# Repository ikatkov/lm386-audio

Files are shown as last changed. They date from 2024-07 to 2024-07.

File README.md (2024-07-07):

# Small audio amplifier

This is LM386-based power amplifier for radio projects. The simplest possible design directly from the datasheet. 

Assembled mostly from salvaged parts and parts of dubious origin.

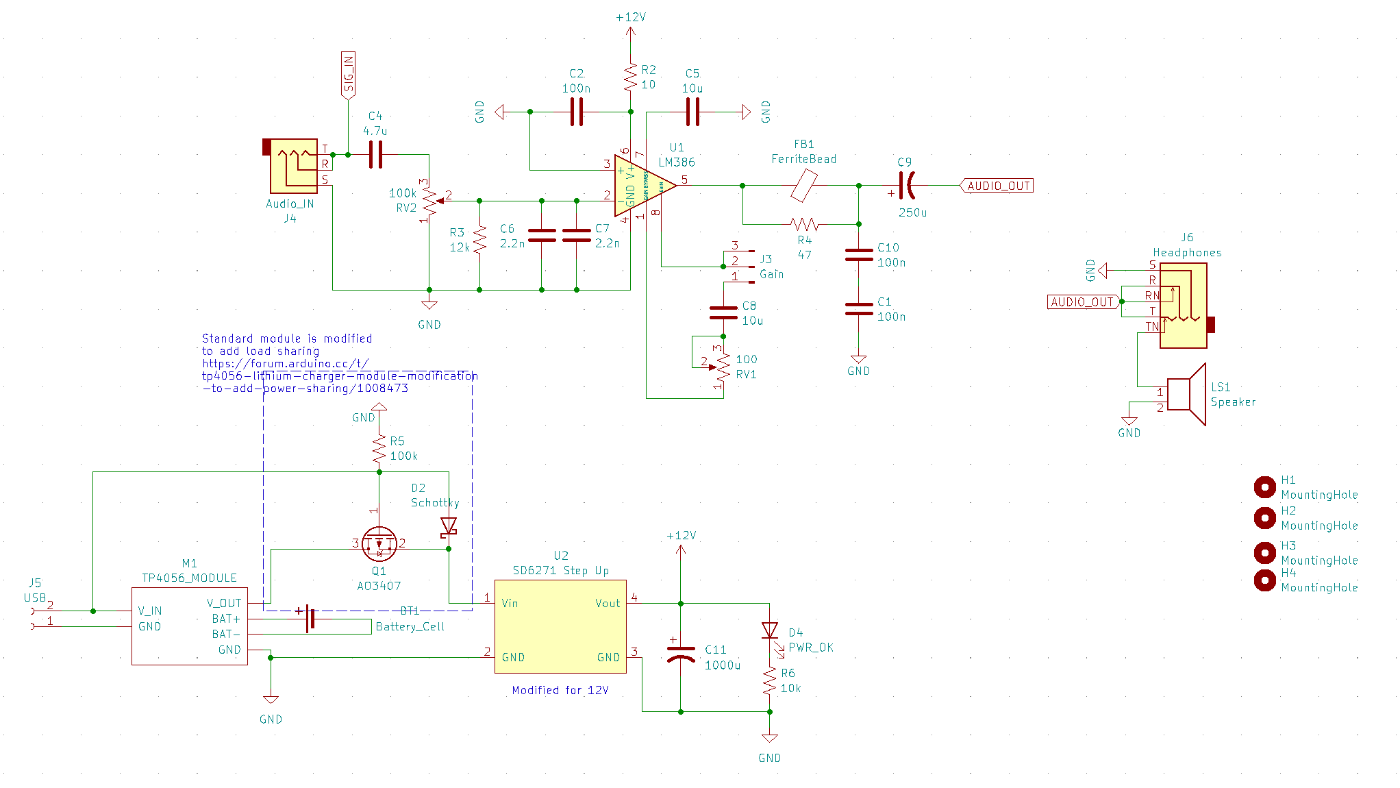
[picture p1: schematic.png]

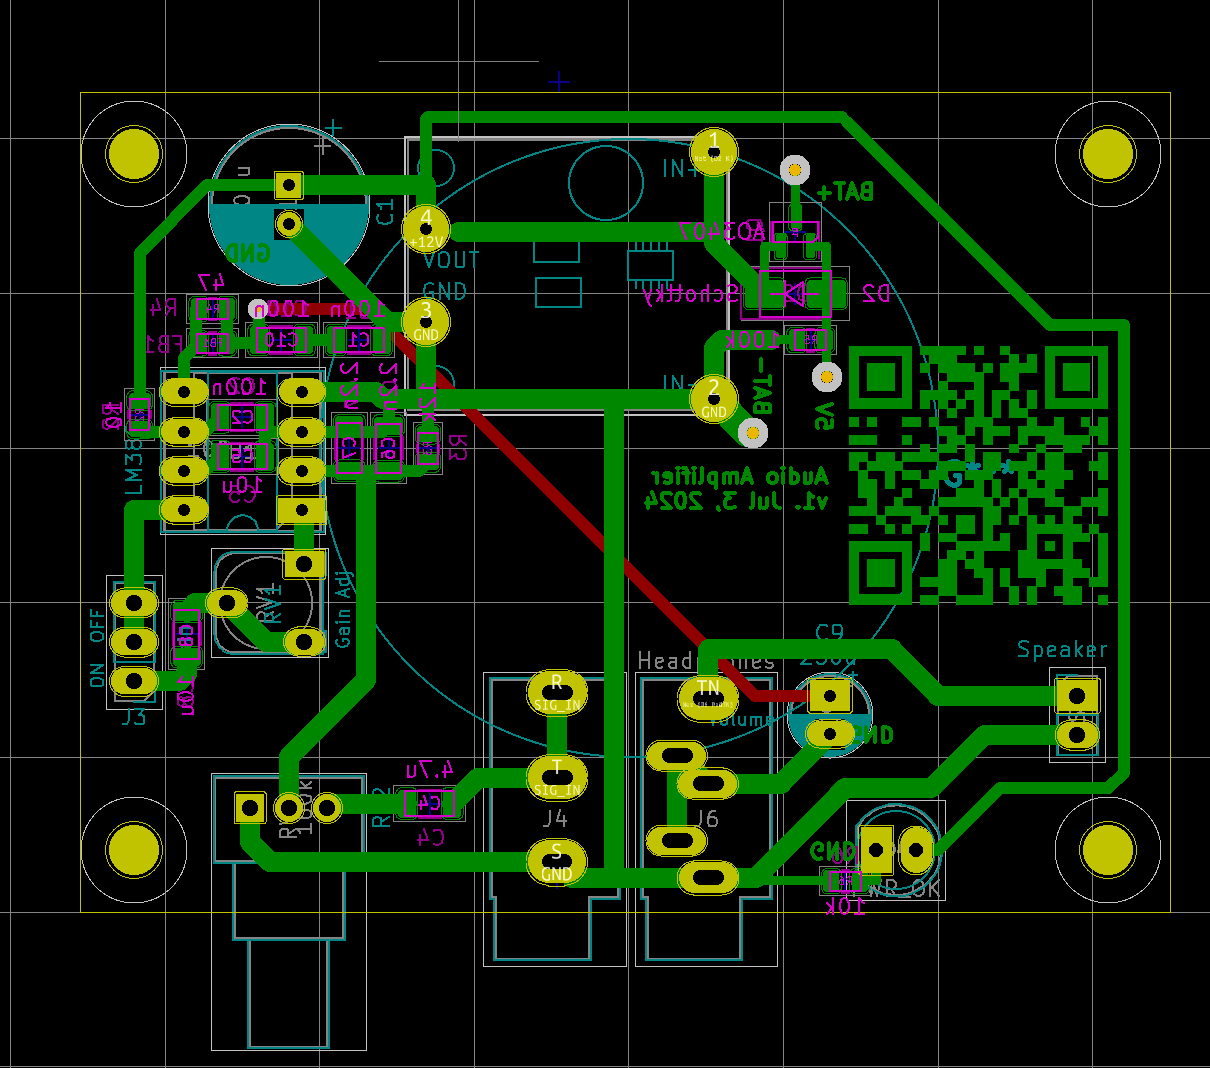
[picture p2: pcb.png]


The charging module and USB socket are not shown on PCB. I had a USB micro socket breakout that I screw directly to the top right corner. USB socket has to stick out from the main board otherwise wide jacks do not fit. The charging module is mounted vertically facing the back panel so that LEDs are visible through the hole.

# Notes

Instead of a hard-to-get 10k logarithmic volume pot, there is a 100k linear with a 12k resistor from the pot wiper to the ground. This is a nice trick.

The output audio signal jack is wired to disconnect the speaker when something, typically headphones, is inserted.

There is a lipo battery inside, with a TP4056 module. The standard PCB was modified for load sharing i.e. when USB power is available, it powers the amplifier directly, bypassing the battery. A  5V boost module

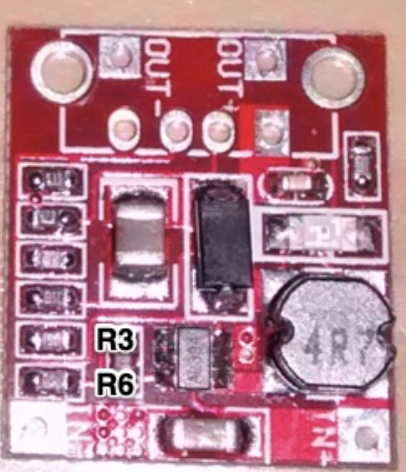
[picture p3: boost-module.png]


was modified for ~12V. Output voltage ripple is ~ 50mV. I presume it is much larger under the load, but the audio amplifier load is very jittery and nonstable as well. LM386 is 0.5W max anyway.

# Enclosure

See 3D printed enclosure files [here](enclosure)

The volume potentiometer stem is not shown. I now assemble first and drill all the holes later. This is significantly faster than high-precision measuring and assembly. 

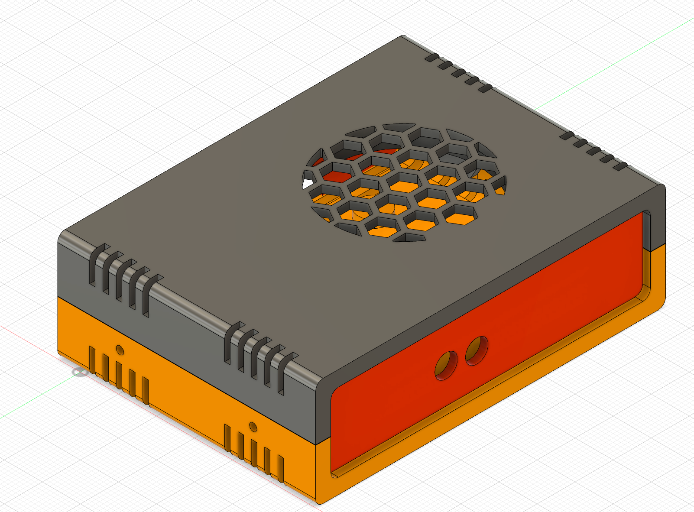
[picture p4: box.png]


# Assembly

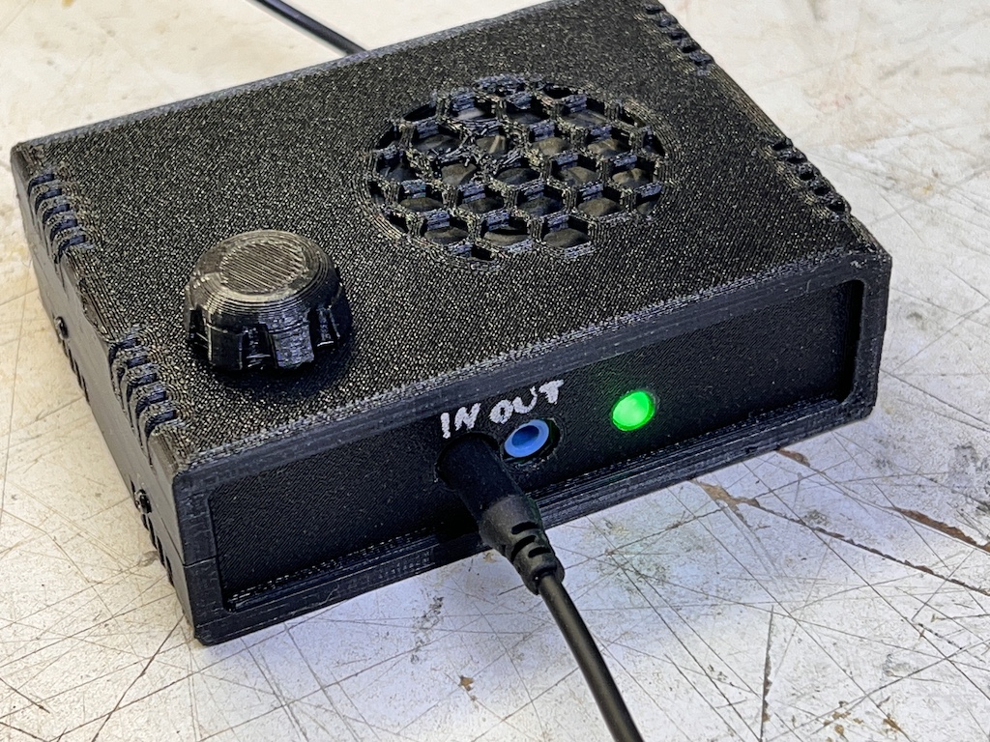
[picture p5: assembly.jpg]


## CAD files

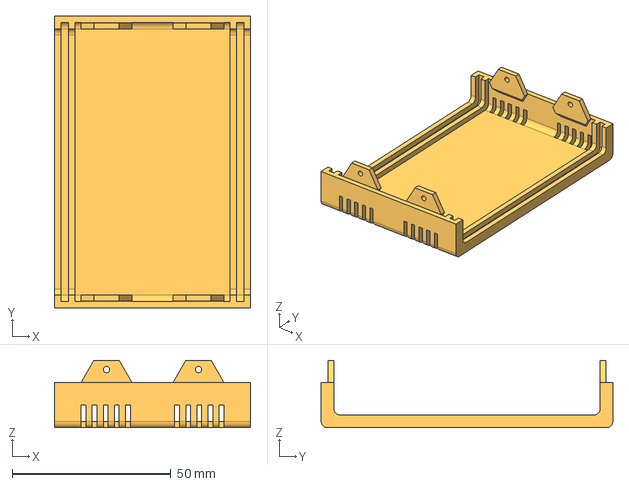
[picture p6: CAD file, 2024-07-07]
enclosure/enclosure-top-shell.step
61.8 x 92.0 x 21.2 mm

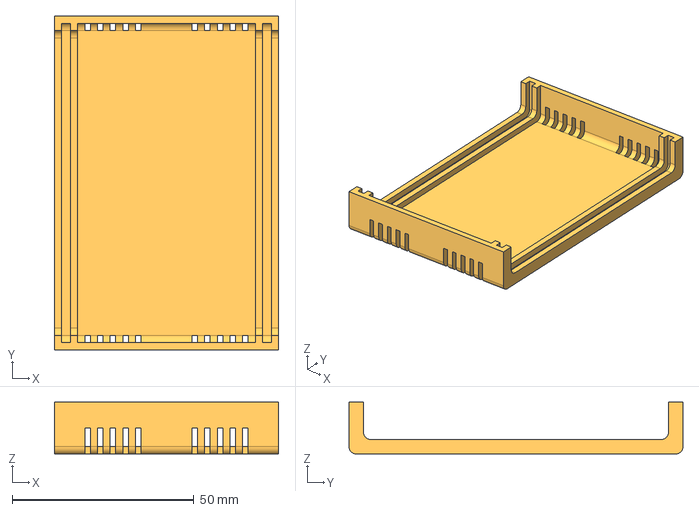
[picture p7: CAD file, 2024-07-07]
enclosure/enclosure-bottom-shell.step
61.8 x 92.0 x 14.3 mm

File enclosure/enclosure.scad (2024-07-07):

/* Box design originally by:
////////////////////////////////////////////////////////////////////
              -    FB Aka Heartman/Hearty 2016     -
              -   http://heartygfx.blogspot.com    -
              -       OpenScad Parametric Box      -
              -         CC BY-NC 3.0 License       -
////////////////////////////////////////////////////////////////////

Improved by jbebel:
http://github.com/jbebel/Ultimate-Box-Maker

To create a box, start by modifying the numerical parameters in the sections
below. This can be accomplished using a release of OpenSCAD newer than 2015.03.
As of the time of writing, this means that a development snapshot is required.
The Thingiverse Customizer may also potentially work, but at the time of
writing, it was inoperable.

The simplest choice is to hand-edit the .scad file. Feature toggles are
annotated with a comment. The other numerical parameters are measurements in
mm. Everything is parametrized, so if you double all the non-feature parameters
you will double the box size in every dimension. Certain parameters are derived
from other parameters. If you wish to override them, you may, but sensible
defaults have been chosen. Notably the design in this revision is particularly
PCB-centric, in that you should start with your PCB size and adjust the margins
around it to determine the box size. If you care more about the box size, you
can set the Length, Width, and Height explicitly, but read the comments around
them.

Once your box is sized appropriately, you can use the Panel modules to design
the holes and text for the front and back panels. Helper variables are provided
to assist you in positioning these holes relative to the PCB, if your holes are
for PCB-mounted components.

When you are ready to print, adjust the values in the "STL element to export"
section, and export each part one at a time.

Experimental options are provided for a screwless design, but these are
untested. In particular, the box fixation tabs may need thicknesses adjusted
in order to have the appropriate flexibility.
*/

// preview[view:north east, tilt:top diagonal]
//----------------------- Box parameters ---------------------------

/* [Box options] */
// - Wall thickness
Thick = 2;
// - Panel thickness
PanelThick = 2;
// - Font Thickness
FontThick = 0.5;
// - Filet Radius
Filet = 2;
// - 0 for beveled, 1 for rounded
Round = 1; // [0:No, 1:Yes]
// - Printer margin around interior cutouts
CutoutMargin = 0.1;
// - Margin between mating parts
PartMargin = 0.1;
// - PCB feet? (x4)
PCBFeet = 1; // [0:No, 1:Yes]
// - Decorations?
Decorations = 1; // [0:No, 1:Yes]
// - Decorations to ventilation holes
Vent = 1; // [0:No, 1:Yes]
// - Decoration-Holes width (in mm)
Vent_width = 1.5;
// - Tolerance (Panel/rails gap on one edge)
PanelThickGap = CutoutMargin + PartMargin;
PanelVerticalGap = PartMargin;
PanelHorizontalGap = CutoutMargin*0 + PartMargin;


/* [Box Fixation Tabs] */
// - Side screw hole (or snap) diameter
ScrewHole = 2;
// - Screw thread major diameter for outer shell
BoxHole = 3;
// Thickness of fixation tabs
TabThick = 2;
// Back left tab
BLTab = 1; // [0:Bottom, 1:Top]
// Back right tab
BRTab = 1; // [0:Bottom, 1:Top]
// Front left tab
FLTab = 1; // [0:Bottom, 1:Top]
// Front right tab
FRTab = 1; // [0:Bottom, 1:Top]
// EXPERIMENTAL: Snap tabs
SnapTabs = 0; // [0:Screws, 1:Snaps]


/* [PCB options] */
// - PCB Length
PCBLength = 53;
// - PCB Width
PCBWidth = 70;
// - PCB Thickness
PCBThick = 1.6;
// You likely need to maintain |TabThick| margin on the left and right for tabs
// and whatnot.
// - Margin between front panel and PCB
FrontEdgeMargin = 0;
// - Margin between back panel and PCB
BackEdgeMargin = 0;
// - Margin between left wall and PCB
LeftEdgeMargin = 0;
// - Margin between right wall and PCB
RightEdgeMargin = 18;
// - Margin between top of PCB and box top.
TopMargin = 20;


/* [PCB_Feet] */
// - Foot height above box interior
FootHeight = 3;
// - Foot diameter
FootDia = 8;
// - Hole diameter, or peg for screwless design
FootHole = 2; // tap size for #4 coarse-thread
// - EXPERIMENTAL Screwless design
Screwless = 0; // [0:Screws, 1:Screwless]
FootFilet = FootHeight/4;

// Foot centers are specified as distance from PCB back-left corner.
// X is along the "length" axis, and Y is along the "width" axis.
// - Foot 1 distance from back PCB edge
Foot1X = 5;
// - Foot 1 distance from left PCB edge
Foot1Y = 5;
// - Foot 2 distance from back PCB edge
Foot2X = 5;
// - Foot 2 distance from right PCB edge
Foot2YFromEdge = 5;
Foot2Y = PCBWidth - Foot2YFromEdge;
// - Foot 3 distance from front PCB edge
Foot3XFromEdge = 5;
Foot3X = PCBLength - Foot3XFromEdge;
// - Foot 3 distance from left PCB edge
Foot3Y = 5;
// - Foot 4 distance from front PCB edge
Foot4XFromEdge = 5;
Foot4X = PCBLength - Foot4XFromEdge;
// - Foot 4 distance from right PCB edge
Foot4YFromEdge = 5;
Foot4Y = PCBWidth - Foot4YFromEdge;


/* [STL element to export] */
// - Top shell
TShell = 0; // [0:No, 1:Yes]
// - Bottom shell
BShell = 1; // [0:No, 1:Yes]
// - Front panel
FPanL = 0; // [0:No, 1:Yes]
// - Back panel
BPanL = 0; // [0:No, 1:Yes]



/* [Hidden] */
// - Shell color
Couleur1 = "Orange";
// - Panel color
Couleur2 = "OrangeRed";

// - making decorations thicker if it is a vent to make sure they go through
// shell
// Add a small number to Thick in case Filet is 0.
Dec_Thick = Vent ? Thick*1.001 + Filet : Thick/2;
// Separate vents with a square pillar by default.
Dec_Spacing = Thick + Vent_width;
// X offset to center of first vent
Dec_Offset = Thick*2 + PanelThick + PanelThickGap*2 + Dec_Spacing - Vent_width/2;

// Resolution based on Round parameter. Set this first number to something
// smaller to speed up processing. It should always be a multiple of 4.
Resolution = Round ? 100: 4;

/* Calculate box dimensions from PCB. If you want a more box-centric design
   where the outer diameter of the box matters more than the margins around
   the PCB you can set these manually. The PCB will still be placedaccording
   to the left and back margins, and if you want to use the screwless box
   design, you will need to set the TopMargin to
   (Height - Thick*2 - FootHeight - PCBThick)
*/
Length = PCBLength + FrontEdgeMargin + BackEdgeMargin + ((Thick + PanelThick + PanelThickGap*2)*2);
Width = PCBWidth + LeftEdgeMargin + RightEdgeMargin + Thick*2;
Height = FootHeight + PCBThick + TopMargin + Thick*2;
echo("Box: ", Length=Length, Width=Width, Height=Height);
// X position inset of mounting holes and tabs
MountInset = Thick*3 + PanelThick + PanelThickGap*2 + ScrewHole*4;

// Calculate panel dimensions from box dimensions.
PanelWidth = Width - Thick*2 - PanelHorizontalGap*2;
PanelHeight = Height - Thick*2 - PanelVerticalGap*2;


/*  Panel Manager

    Use the below 4 modules to produce holes and text on the front and back
    panels. The holes modules should contain instances of SquareHole or
    CylinderHole defined later in this file. The text modules should contain
    instances of LText or CText defined later in this file. It is
    recommended to use variables that you define for your needs to create
    the size and positions of these objects.
*/

// Calculate board-relative positions with respect to the panel, for
// convenience in placing panel elements.
TopOfBoardWRTPanel = FootHeight + PCBThick - PanelVerticalGap;
LeftEdgeOfBoardWRTFPanel = LeftEdgeMargin - PanelHorizontalGap;
LeftEdgeOfBoardWRTBPanel = RightEdgeMargin - PanelHorizontalGap;
// Visible panel edges
PanelBottomEdge = Thick - PanelVerticalGap;
PanelTopEdge = PanelHeight - Thick + PanelVerticalGap;
PanelLeftEdge = Thick - PanelHorizontalGap;
PanelRightEdge = PanelWidth - Thick + PanelHorizontalGap;






// ------- You probably don't need to modify anything below this line. --------


/* Generic rounded box

    Produces a box of the specified dimensions. Corners are rounded
    according to Filet and Resolution parameters.

    Arguments:
    xshrink: the amount to reduce the length on one end compared to the full
        length
    yzshrink: the amount to reduce the width or height on one edge compared
        to the full box
*/
module RoundBox(xshrink=0, yzshrink=0) {
    Filet = (Filet > Thick*2) ? Filet - yzshrink : Filet;
    translate([xshrink, yzshrink, yzshrink]) {
        rotate([90, 0, 90]) {
            linear_extrude(height=Length - xshrink*2) {
                translate([Filet, Filet, 0]) {
                    offset(r=Filet, $fn=Resolution) {
                        square([Width - 2*yzshrink - 2*Filet, Height - 2*yzshrink - 2*Filet]);
                    }
                }
            }
        }
    }
}


/*  MainBox: Main box module
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

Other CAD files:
enclosure/enclosure-side-panel.step
enclosure/enclosure.f3z

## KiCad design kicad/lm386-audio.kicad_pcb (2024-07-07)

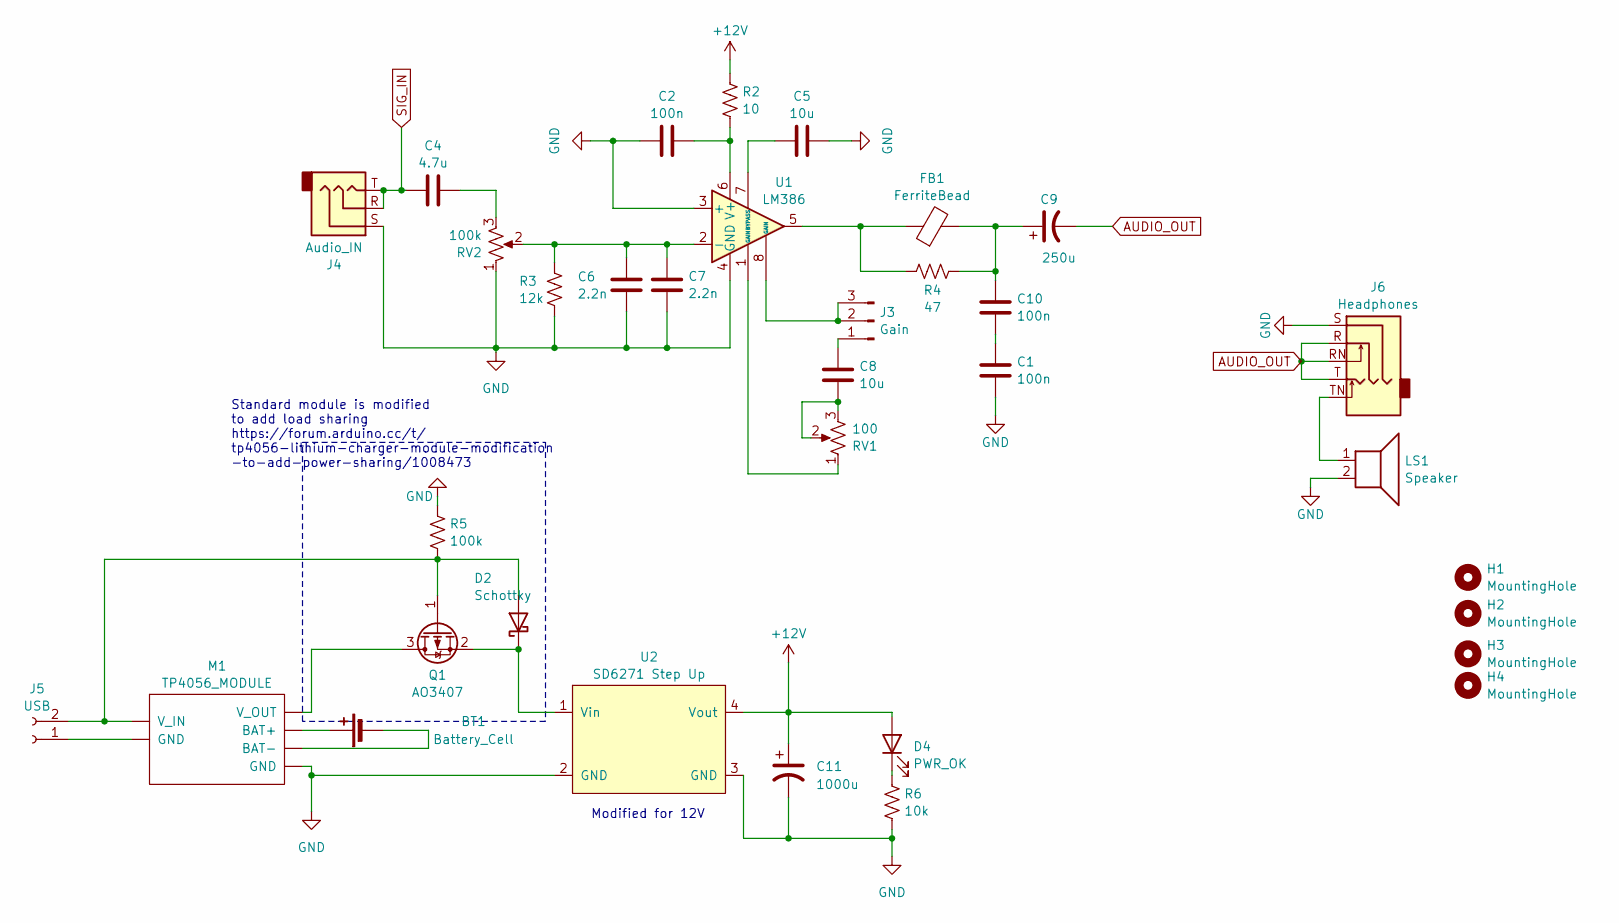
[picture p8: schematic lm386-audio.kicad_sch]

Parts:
BT1: Battery_Cell
C1, C2, C10: 100n; C_1206_3216Metric
C4: 4.7u; C_1206_3216Metric
C5, C8: 10u; C_1206_3216Metric
C6, C7: 2.2n; C_1206_3216Metric
C9: 250u; CP_Radial_D5.0mm_P2.50mm
C11: 1000u; CP_Radial_D10.0mm_P2.50mm
D2: Schottky; D_SMA
D4: PWR_OK; LED_D5.0mm
FB1: FerriteBead; R_0805_2012Metric
H1, H2, H3, H4: MountingHole; MountingHole_3.2mm_M3
J3: Gain; PinHeader_1x03_P2.54mm_Vertical
J4: Audio_IN; Jack_3.5mm_CUI_SJ1-3533NG_Horizontal
J5: USB
J6: Headphones; Jack_3.5mm_CUI_SJ1-3535NG_Horizontal
LS1: Speaker; PinHeader_1x02_P2.54mm_Vertical
M1: TP4056_MODULE; TP4056-18650
Q1: AO3407; SOT-23
R2: 10; R_0805_2012Metric
R3: 12k; R_0805_2012Metric
R4: 47; R_0805_2012Metric
R5: 100k; R_0805_2012Metric
R6: 10k; R_0805_2012Metric
RV1: 100; Potentiometer_Runtron_RM-065_Vertical
RV2: 100k; Potentiometer_Alps_RK09Y11_Single_Horizontal
U1: LM386; DIP-8_W7.62mm_Socket_LongPads
U2: SD6271 Step Up; SD6271_StepUp

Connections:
+12V: C11.1, D4.2 (A), R2.1, U2.4 (Vout)
AUDIO_OUT: C9.2, J6.R, J6.RN, J6.T
GND: C1.1, C2.1, C5.1, C6.1, C7.1, C11.2, J4.S, J6.S, LS1.2, M1.4 (GND), R3.1, R5.2, R6.2, RV2.1, U1.3 (+), U1.4 (GND), U2.2 (GND), U2.3 (GND)
unnamed: BT1.1 (+), M1.5 (BAT+)
unnamed: BT1.2 (-), M1.6 (BAT-)
unnamed: C1.2, C10.1
unnamed: C4.2, RV2.3
unnamed: C8.1, RV1.2, RV1.3
unnamed: C9.1, C10.2, FB1.2, R4.2
unnamed: D2.2 (A), J5.2, M1.1 (V_IN), Q1.1 (G), R5.1
unnamed: D2.1 (K), Q1.2 (S), U2.1 (Vin)
unnamed: D4.1 (K), R6.1
unnamed: FB1.1, R4.1, U1.5
unnamed: C8.2, J3.1
unnamed: J3.2, J3.3, U1.8 (GAIN)
unnamed: J5.1, M1.2 (GND)
unnamed: J6.TN, LS1.1
unnamed: M1.3 (V_OUT), Q1.3 (D)
unnamed: RV1.1, U1.1 (GAIN)
unnamed: C6.2, C7.2, R3.2, RV2.2, U1.2 (-)
unnamed: C5.2, U1.7 (BYPASS)
unnamed: C2.2, R2.2, U1.6 (V+)
SIG_IN: C4.1, J4.R, J4.T

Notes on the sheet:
Standard module is modified to add load sharing https://forum.arduino.cc/t/ tp4056-lithium-charger-module-modification -to-add-power-sharing/1008473
Modified for 12V

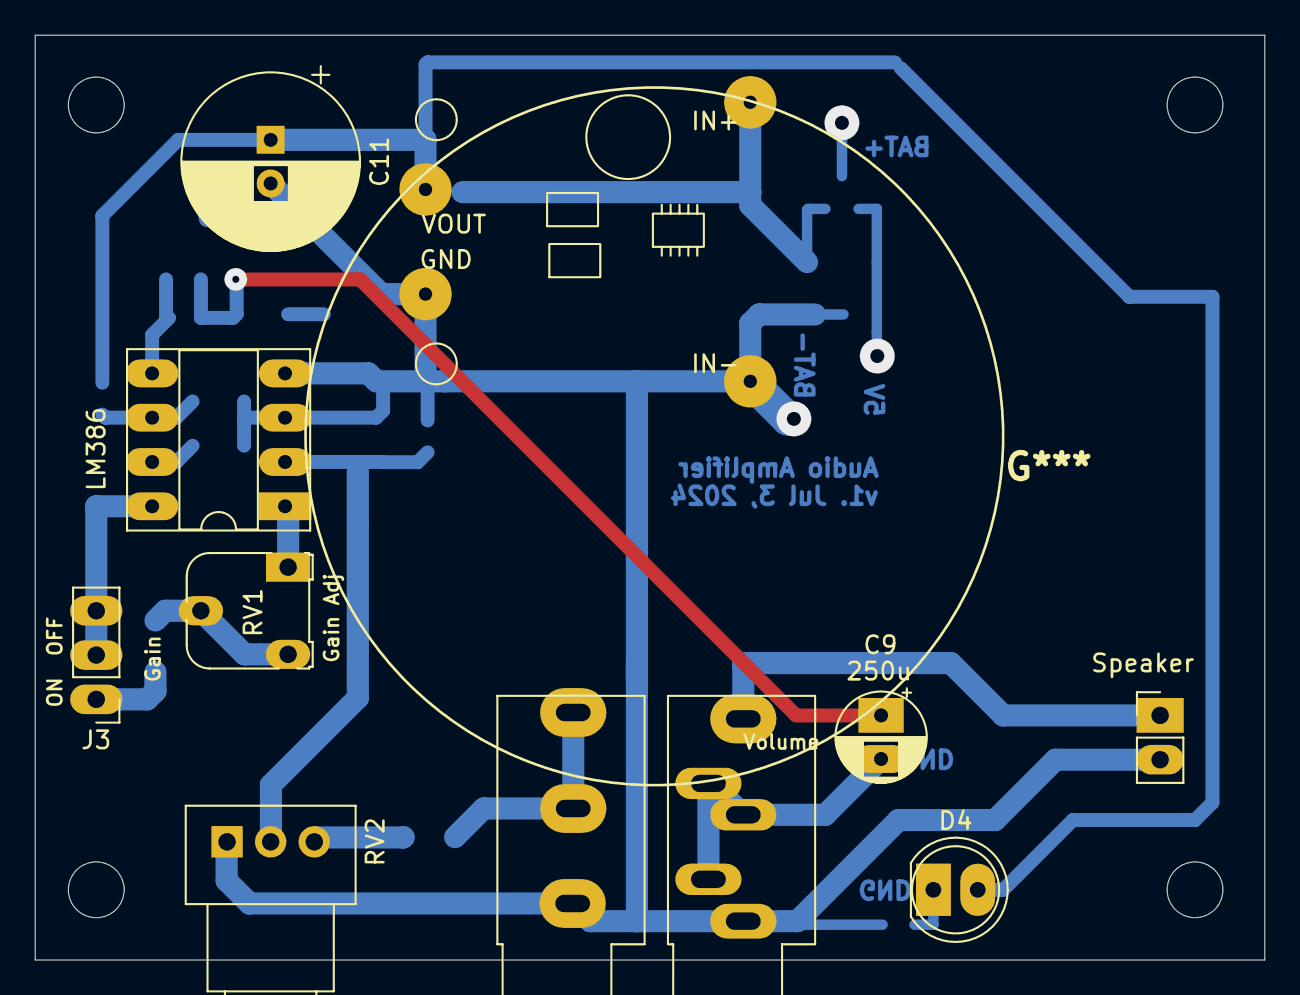
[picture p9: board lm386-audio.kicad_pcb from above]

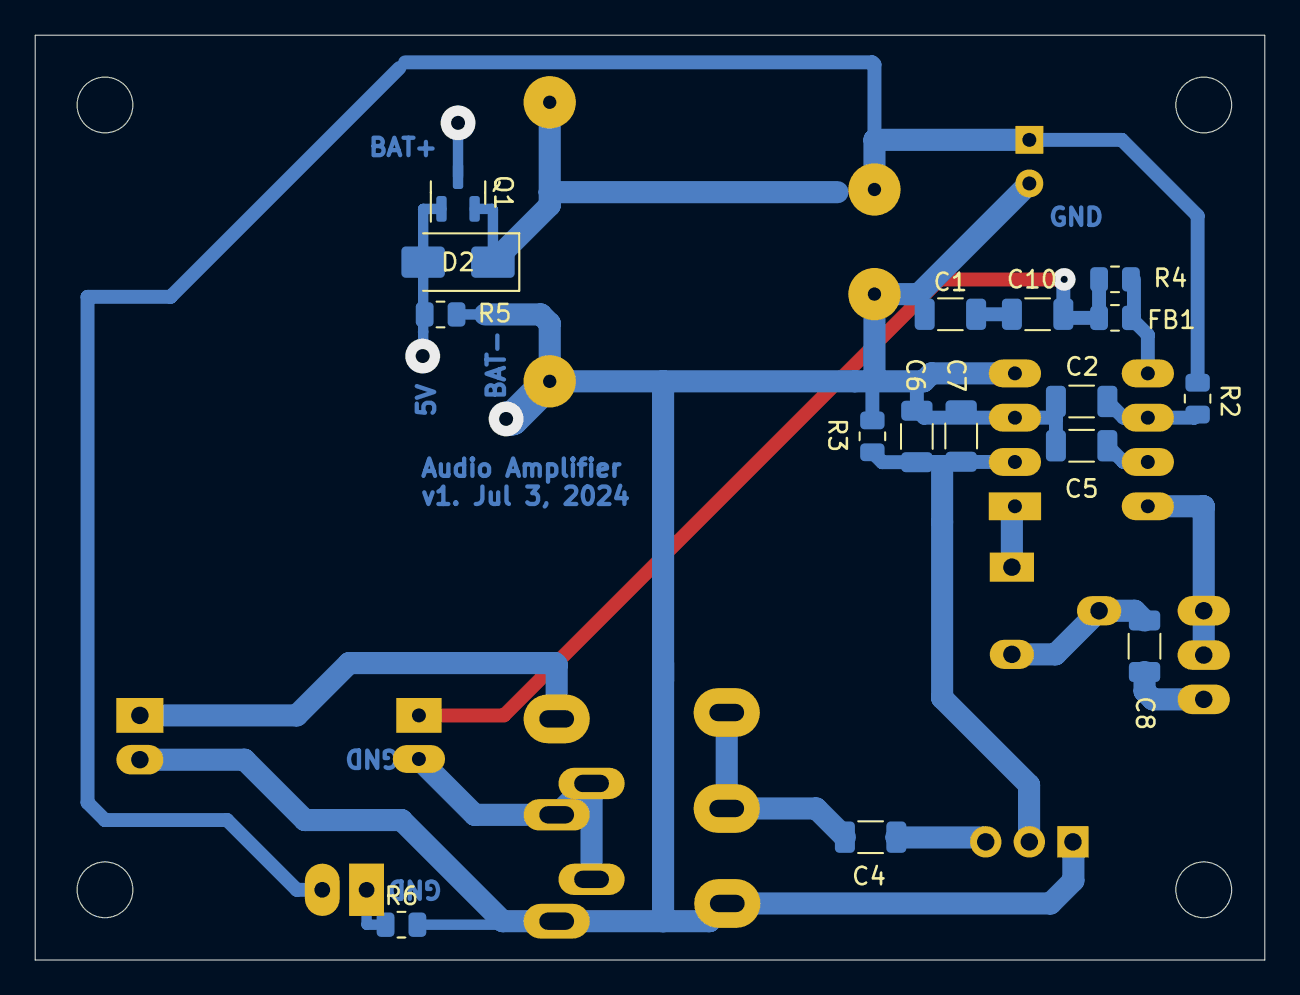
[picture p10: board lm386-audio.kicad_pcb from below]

Board: 4 copper layers, 70.5 x 53.0 mm, 31 parts (16 on the bottom side), 19 nets.
